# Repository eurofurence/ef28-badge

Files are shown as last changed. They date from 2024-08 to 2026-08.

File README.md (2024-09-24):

# Eurofurence 28 Cyber Badge

The cyber LED-Badge is a unique piece of wearable tech. At its core is a rigid
PCB (printed circuit board), assembled with electronic components, carefully
designed to be both functional and visually striking. On the back, you’ll find
a battery pack that powers the badge, ensuring that it can light up in a
spectrum of vibrant colors throughout the event.

The badge features 17 RGB LEDs, which can be controlled to display different
colors and patterns, allowing you to customize your experience. Whether you
want to flash your favorite colors, sync up with others, or simply let your
badge pulse with light as you move through the convention, the choice is yours.

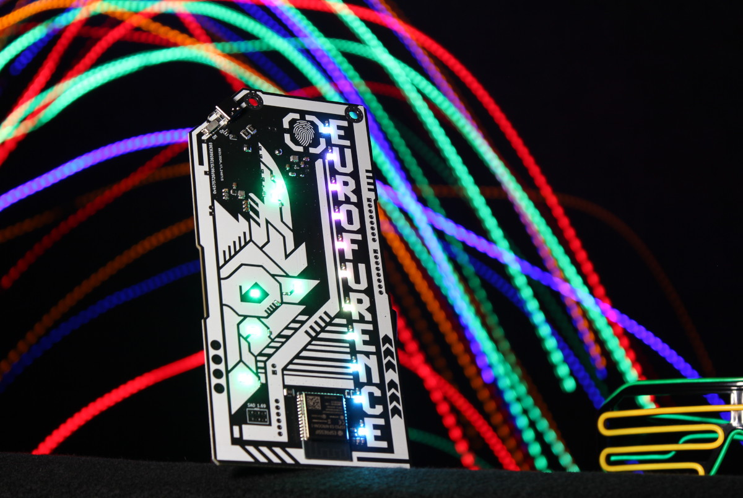
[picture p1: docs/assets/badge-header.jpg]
Picture of the badge


## Technical Details

You can find the full schematics and PCB files in the
[Hardware Details](#hardware-details) section.

- Height: 15.9 cm
- Width: 7.7 cm
- Weight (w/o batteries): 56 g
- Weight (with batteries): ~126 g
- LEDs: 17x WS2812B RGB LEDs
- CPU: ESP32-S3-WROOM-1-N16R8 (Dual-Core, 16MB of Flash, Bluetooth, Wi-Fi)
- Battery holder: 3x AA batteries
- Runtime: Depending on the operation mode and used features, several to many hours
- Unpopulated headers: 2x8 GPIO, SAO 1.69
- User input: 2 touch buttons
- Attachment: Dual-nylon-loop lanyard (included)
- Connectivity: USB-C connector for powering or programming
- Power: Mechanical power switch

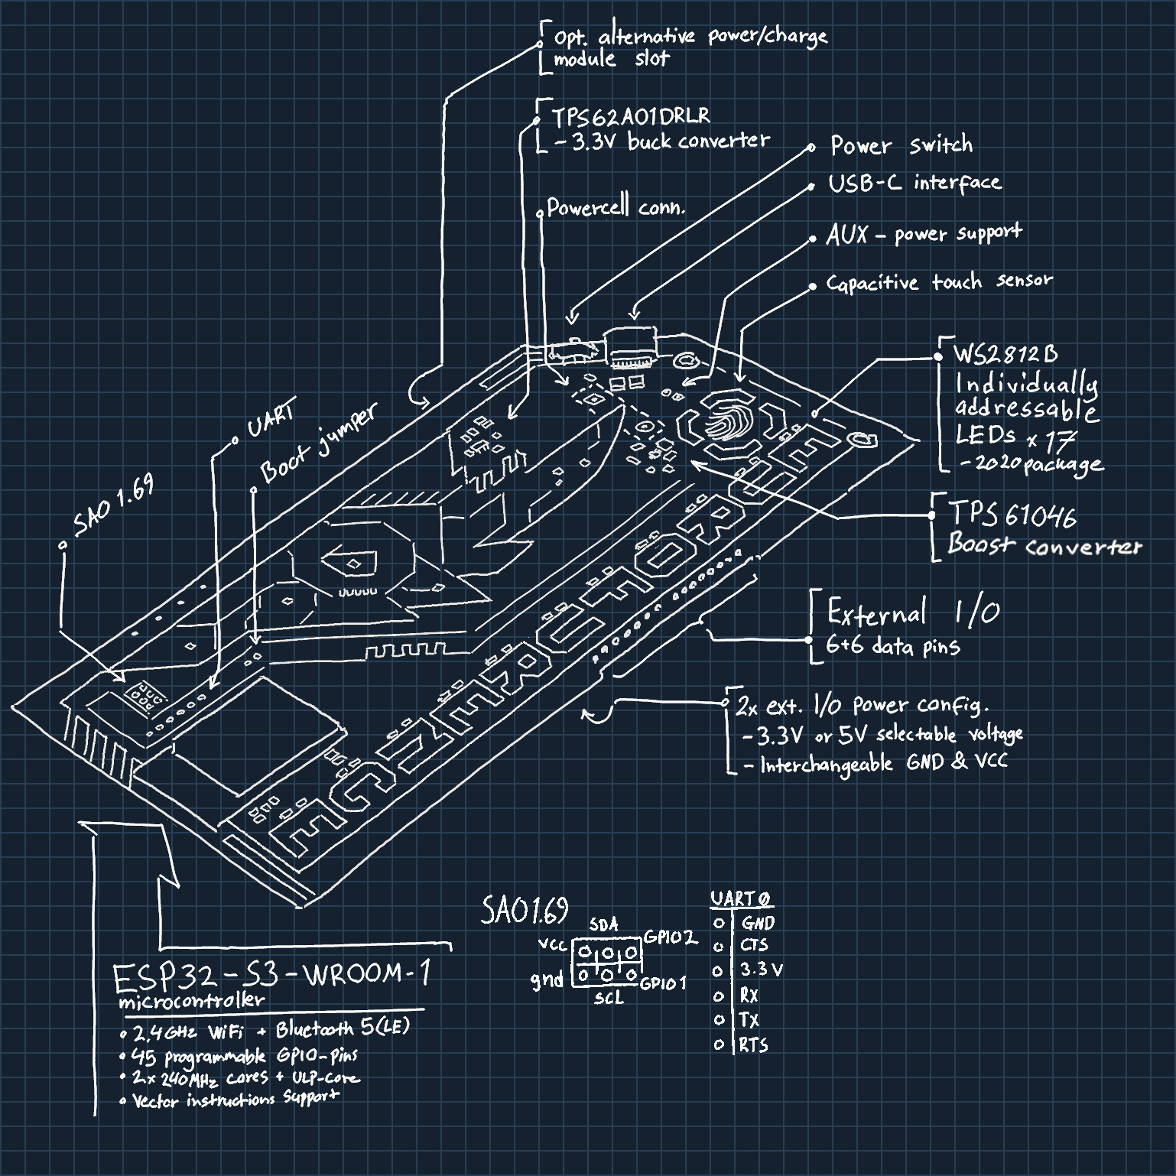
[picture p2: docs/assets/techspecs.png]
Technical drawing of the badge


# Usage and features

See this page: [How to use your badge](https://www.eurofurence.org/EF28/badge/manual)

## Serial Output / Logging

The badge logs most of its actions and current state onto the serial USB
console. It is available after connecting the badge via USB to your computer
and uses 115200 Baud 8N1.

To read the serial output you can use the serial monitor of your choice, for
example, the integrated serial monitor within VS Code (`CTRL + ALT + S`):

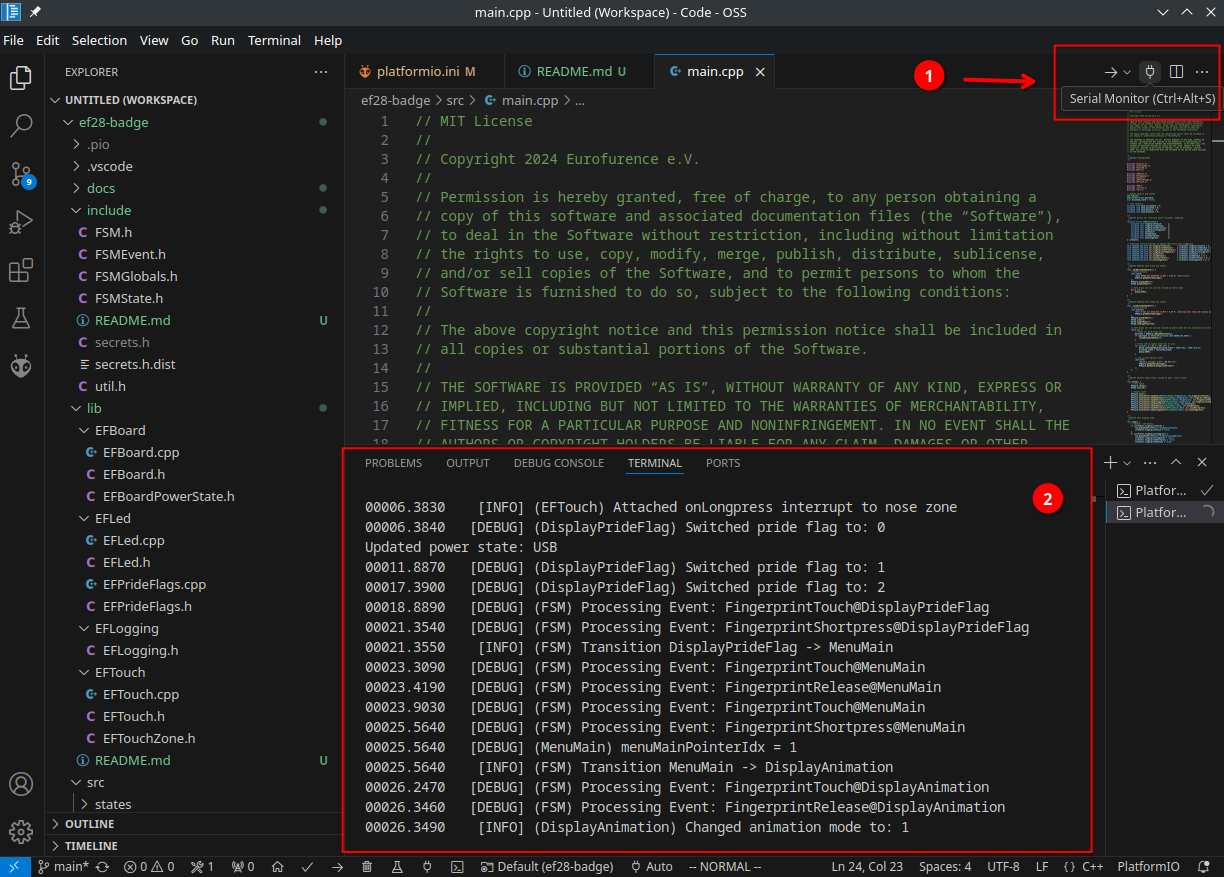
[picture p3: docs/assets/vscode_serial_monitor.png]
Screenshot: Using the serial monitor of VS Code


You can also use your favorite serial monitor, for example [minicom](https://salsa.debian.org/minicom-team/minicom):
`minicom -D /dev/ttyACM0 -b 115200`

## Note on LED brightness

You can configure the brightness of your badge, see the manual [How to use your badge](https://www.eurofurence.org/EF28/badge/manual). If you modify your firmware, do not push the LEDs too hard. We limited the brightness on purpose to around 45 of 255 since the 5V boot converter cannot handle more. If you use just one color channel, values up to 100/255 might work. But they are plenty bright at 45 of 255. Higher values cause the 5V rail to break down and the LEDs start flickering badly.

# Building Your Own Firmware

The badge firmware is built using [PlatformIO](https://platformio.org/), an
extension for [Visual Studio Code](https://code.visualstudio.com/) that allows
beginners to quickly get hacking.

### Building with Visual Studio Code (VCS)

To set up your development environment, you need to:

1. Install Visual Studio Code and PlatformIO, as described in the official
   [PlatformIO documentation](https://docs.platformio.org/en/latest/integration/ide/vscode.html#installation)
2. Clone this repository to a suitable location (here: `~/git/ef28-badge`)
3. Open the project under `~/git/ef28-badge` using the PlatformIO IDE
4. Copy `include/secrets.h.dist` to `include/secrets.h` and adjust as needed
5. Execute the build by pressing the build button (1) or using the hotkey (`CTRL + ALT + B`)
6. Check that your build was successful (2)

_Note: The first build can take a while since additional tools and libraries
may need to be downloaded_

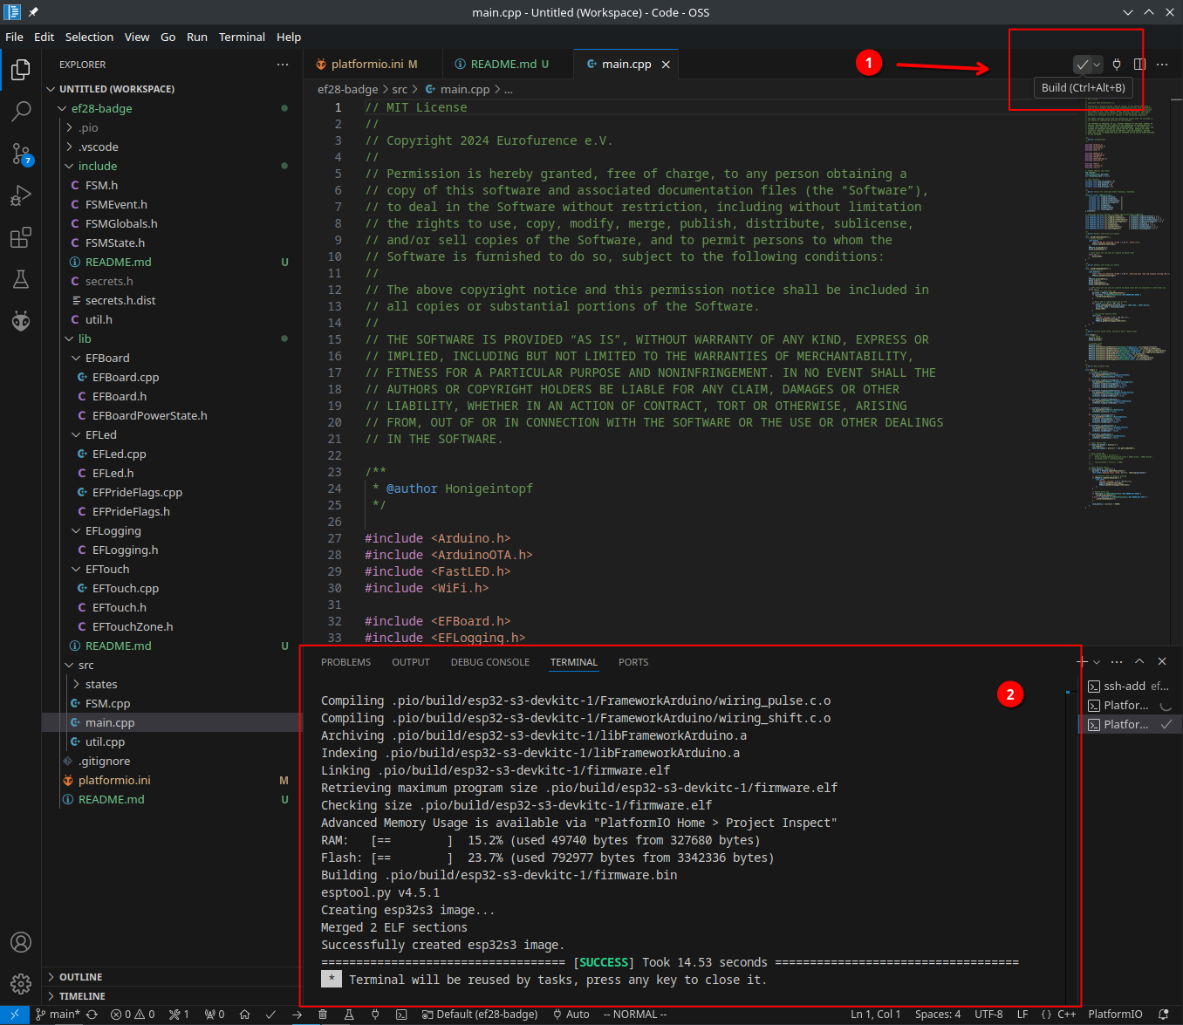
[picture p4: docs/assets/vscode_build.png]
Screenshot: Building the firmware using VS Code


### Building from CLI

You can archive most things with the `pio` command from PlatformIO.

* Build firmware: `pio run`
* Upload firmware: `pio run --target upload`
* Clean generated files: `pio run --target clean`
* Attach serial monitor: `pio device monitor`

## Component Overview

The core of this firmware is implemented as a tick-based finite state machine
(FSM). Each operation mode is reflected by a corresponding FSM state.
Interrupts, e.g., from touch zones, trigger events which will be processed by
the FSM in the order they occurred during each tick. Every FSM state can define
its own tick rate. Board features, such as LEDs and touch zones, are available
via easy to use high-level APIs (see `lib/`).

A quick overview of the firmware components:

- `main.cpp`: The main entry point for the firmware. Initializes everything and
  ignites the FSM.
- `include/`: C++ headers
- `include/secrets.h(.dist)`: Custom defines for Wi-Fi and OTA
- `lib/EFBoard/`: Low-level initialization and power management
- `lib/EFLed/`: High-level interface to board LEDs, uses
  [FastLED](https://fastled.io/) under the hood
- `lib/EFLogging/`: Basic serial logging facilities
- `lib/EFTouch/`: High-level interface to touch sensors
- `src/FSM.cpp`: Implementation of the FSM logic
- `src/states/`: Implementation of all FSM states

## Flashing

After you've built your firmware, you can flash it by either connecting the
badge via USB to your computer, or by using over-the-air (OTA) updates.

_Note: OTA updates are only supported after an initial flash using a USB
connection_

### USB

To flash the firmware via USB, you need to:

1. Have a successful build of your firmware
2. Connect the badge via USB to your computer
3. **Close all serial monitors** that use the badges USB device
4. Click the upload button (1) or use the hotkey (`CTRL + ALT + U`)
5. Wait for the flashing to finish (2). Your badge will reboot after flashing.

_Note: Linux users might need to install the
[PlatformIO udev rules](https://docs.platformio.org/en/stable//core/installation/udev-rules.html)
prior to the first flashing._

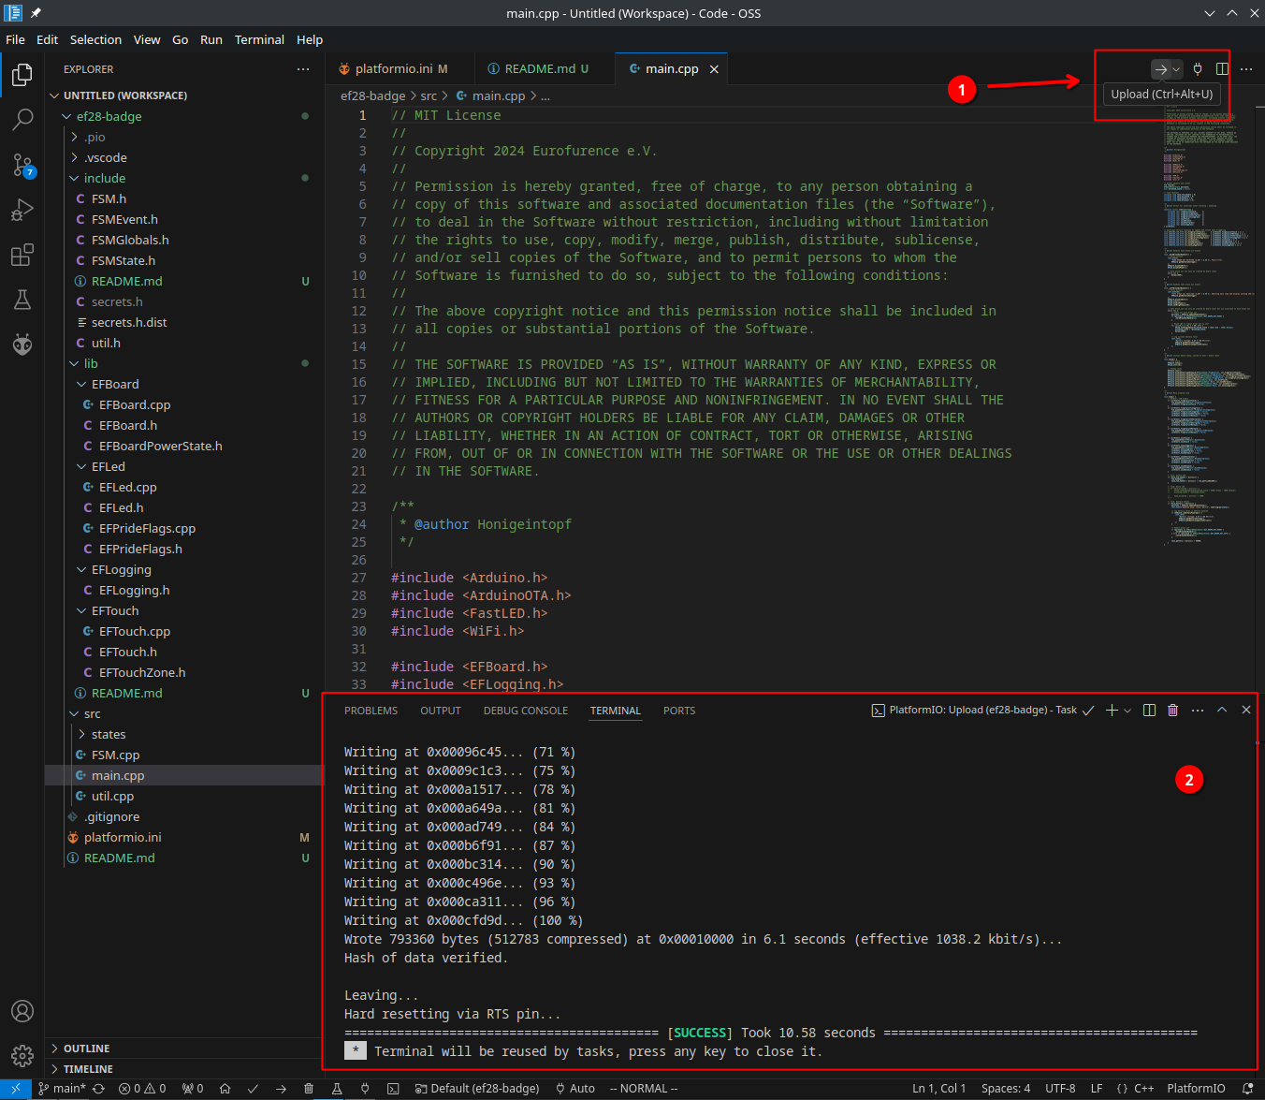
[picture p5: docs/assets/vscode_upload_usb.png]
Screenshot: Flashing the firmware via USB using VS Code


#### Notes and Pitfalls

If you encounter issues flashing via USB, try the following:

* Some USB cables or ports are flaky. Try a different USB port or change the
  USB-C -> USB-C cable to a USB-A -> USB-C or vice versa.
* Make sure no program is opening the serial port while you flash. For example
  serial monitors in auto-connect mode.
* If it still fails, bridge the boot-pins when turning on. The badge should
  load into a simple bootloader and wait.

### Over-the-Air Updates (OTA)

If you want to flash the badge using over-the-air updates (OTA), it must be
connected to the same Wi-Fi network as your computer.

To flash a badge using OTA, you need to:

1. Make sure to have the correct Wi-Fi credentials supplied in `include/secrets.h`
2. Determine the badge IP address
    - This can be done by connecting your badge to your computer, opening the
      serial monitor, and letting it connect to your Wi-Fi. After a successful
      connection, the badge will print its IP and MAC addresses to the serial console.
3. Uncomment all `upload_*` entries in your `platformio.ini` and adjust
   `upload_port` to the IP address of your badge.
4. Ensure that the badge is in OTA mode
5. Click the upload button or use the hotkey (`CTRL + ALT + U`)
6. Wait for the flashing to finish. The badge will display the OTA progress
   using the LED bar, and the dragon eye will flash three times after a
   successful OTA update.

# Hardware Details

All hardware details, schematics, and PCB files of the badge are released as
[Open Source Hardware](https://www.oshwa.org/). Feel free to share, use, remix,
and extend them to your likings.

You can find the full [KiCad](https://www.kicad.org/) files inside the
`hardware` directory.

For convenience, here is an exported PDF version of the schematics:

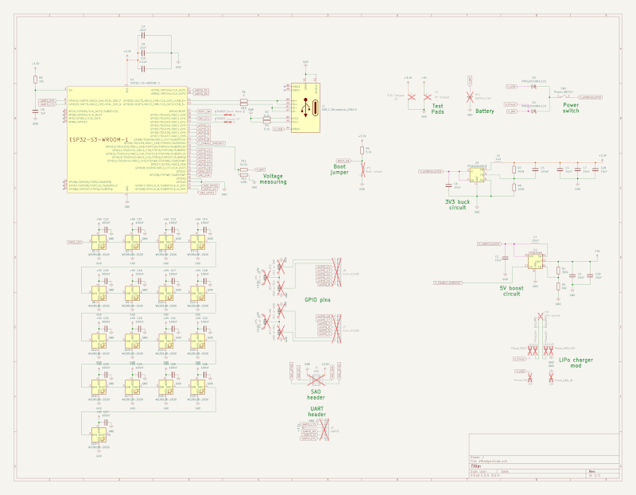
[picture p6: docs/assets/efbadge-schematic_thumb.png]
Screenshot: Schematics thumbnail


# Releases

The release-versions are based on [CalVer](https://calver.org/), with the pattern `vYYYY.MM.DD(-SUB)` where `SUB` is for potential sub-daily releases.

# Useful links

* ESP32-S3 Pin-out and functions: https://github.com/atomic14/esp32-s3-pinouts

# Credits

This badge was designed, crafted and programmed with much love and dedication
by: [DarkRat](https://github.com/dunkelratte), [Token](https://github.com/TokenRat),
[Irah](https://github.com/tridekdu), [Honigeintopf](https://github.com/ngandrass).

The wonderful artwork is done by [Fleeks](https://www.furaffinity.net/user/fleeks).

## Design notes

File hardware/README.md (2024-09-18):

# Hardware

This is a [KiCad](https://www.kicad.org/) project.

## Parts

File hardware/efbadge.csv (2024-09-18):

Comment | Designator | Footprint | LCSC
Battery_Cell | BT1 | Battery:BatteryHolder_TruPower_BH-331P_3xAA
CS2012X5R475K250NRE | C1,C4 | Capacitor_SMD:C_0805_2012Metric | C2918489
0.1uF | C10 | Capacitor_SMD:C_0603_1608Metric | C2846678
GRM188B30J226MEA0D | C2 | Capacitor_SMD:C_0603_1608Metric | C15500
1uF | C3,C8 | Capacitor_SMD:C_0603_1608Metric | C309479
29pF | C5 | Capacitor_SMD:C_0603_1608Metric | C880276
160pF | C6 | Capacitor_SMD:C_0603_1608Metric | C565568
10uF | C7 | Capacitor_SMD:C_0603_1608Metric
22uF | C9 | Capacitor_SMD:C_0603_1608Metric | C15500
WS2812B-2020 | D1,D2 | LED_SMD:LED_WS2812B-2020-Original_PLCC4_2.0x2.0mm | C965555
PMEG2010BEA,115 | D3,D4,D5 | Diode_SMD:D_SOD-323 | C455041
USB_C_Receptacle_USB2.0 | J1 | Connector_USB:USB_C_Receptacle_G-Switch_GT-USB-7010ASV | C165948
5V Testpad | J2 | Connector_PinHeader_2.54mm:PinHeader_1x02_P2.54mm_Vertical
3.3V Testpad | J3 | Connector_PinHeader_2.54mm:PinHeader_1x02_P2.54mm_Vertical
CWCI0603F-4R7KT | L1,L2 | Inductor_SMD:L_0603_1608Metric | C917344
27 | R1,R2 | Resistor_SMD:R_0603_1608Metric | C4197
5.1k | R3,R4 | Resistor_SMD:R_0603_1608Metric | C445832
200k | R5 | Resistor_SMD:R_0603_1608Metric | C394540
620k | R6 | Resistor_SMD:R_0603_1608Metric | C220714
550k | R7 | Resistor_SMD:R_0603_1608Metric | C2933236
100k | R8 | Resistor_SMD:R_0603_1608Metric | C2934392
10k | R9 | Resistor_SMD:R_0603_1608Metric | C209220
Power_SWITCH | SW1 | Button_Switch_SMD:SW_SPDT_PCM12 | C128955
ESP32-S3-WROOM-1 | U1 | PCM_Espressif:ESP32-S3-WROOM-1 | C2980297
TPS61040DDC | U2 | Package_TO_SOT_SMD:SOT-23-5 | C2678707
TPS62200DBV | U3 | Package_TO_SOT_SMD:SOT-23-5 | C9048

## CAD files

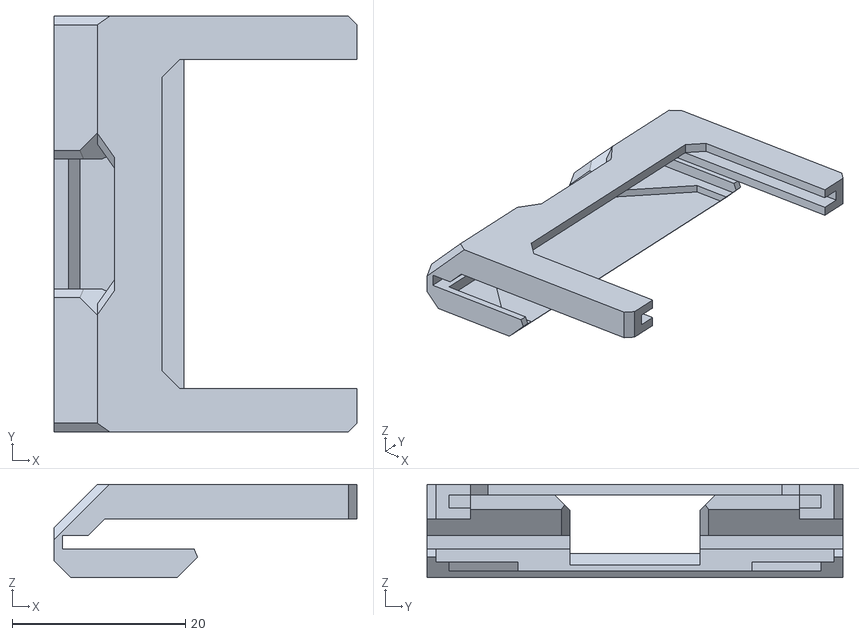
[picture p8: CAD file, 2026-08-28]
hardware/3dprint/oled_mount.stl
35.0 x 48.0 x 10.8

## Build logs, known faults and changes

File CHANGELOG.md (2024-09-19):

# EF28 Cyber LED Badge

## v2024-09-19-beta

* Add beta game mode R. By pressing the nose you transmit your color to nearby badges. The more nose-boop, the more you 'spread' you color.

## v2024.09.07

* Initial release

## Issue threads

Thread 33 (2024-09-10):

Battery measurement is off

TokenRat, 2024-09-10:
**What is the problem**

Currently, getBatteryVoltage uses a factor for the internal ADC of 3.5V instead of 3.3v, what it should be. The reason is: If we use 3.5 as the factor, when on batteries, we go into soft-brownout detection at around 3.36V, which is right what we want. (Measured with multimeter on the batteries). Why is this? What is wrong with the formular?

Also, when on USB and monitoring serial, we get values which a very off. If we use 3.3 as a factor, we measure almost 0.2V too little. Using 3.5 as the factor still does not get the perfect result.

Maybe someone can spot the mistake…

Code: https://github.com/eurofurence/ef28-badge/blob/eefaa05d0f5d9e829db166581c0f541a6f17a42c/lib/EFBoard/EFBoard.cpp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

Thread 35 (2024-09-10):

Using the ULP processor for LED animations

TokenRat, 2024-09-10:
**Your feature request**

The ULP is *barely* too slow to bit-bang the WS2812 LEDs according to the timing specs. But who knows, how tolerant they are? With some well-timed NOPs or some other tricks, we might be able to draw patterns per GPIO from the ULP.

The main processor then would write the patterns into flash and go to sleep, while the ulp reads them and displays them, until wakeup. This would reduce the power consumption and be a pretty cool trick. I played around a bit already, but got no results so far.

Of course, any WiFi or other function would not work in this state.

nponsard, 2024-10-10:
I managed to control the leds from the ULP https://github.com/nponsard/ef28-badge/blob/rust-no-std/coprocessor/src/main.rs .

I made it so it generates the code to drive all the leds and then execute it so the timing is always the same.

To initialize I do
```asm
lui	a2,0x80000
lui	a1,0xa
addi    a1,a1,1024
```
so I can turn on and off the gpio 21 with a 2-bytes instruction instead of a 4-bytes instructions

Turn on :
```
sw      a2,4(a1)
```

Turn off :

```asm
sw      a2,8(a1)
```

then I use NOP instructions as delays:
- 0 for T0H (bit 0, number of NOP to wait before turning off)
- 2 for T1H (bit 1, number of NOP to wait before turning off)
- 4 for T0L (bit 0, number of NOP to wait before encoding the next bit)
- 2 for T1L (bit 1, number of NOP to wait before encoding the next bit)

Generating a program to drive the 17 leds uses 4 908 bytes.
I tried previously with loops but it messes up the timing.

For example , to send 010 :
```asm
// configure the registers once
lui	a2,0x80000
lui	a1,0xa
addi    a1,a1,1024
//send the data
sw      a2,4(a1) // turn on
sw      a2,8(a1) // turn off
nop
nop
nop
nop
sw      a2,4(a1) // turn on
nop
nop
sw      a2,8(a1) // turn off
nop
nop
sw      a2,4(a1) // turn on
sw      a2,8(a1) // turn off
nop
nop
nop
nop
```

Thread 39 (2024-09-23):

Complete USB-Driven mode

MeisterLi, 2024-09-23:
**Your feature request**
I would like to put the EF LED Bade into my PC and drive it internally via USB there. It would be nice if we could issue commands via that serial connection to change patterns/display modes. I am not very versed with PlatformIO and C++ and I have looked into it a bit to see if I could find this option, but I wasn't able to figure out if this was a feature already.

I was able to connect the device via Wifi to my home network as well, but from what I can see, that does not allow setting anything yet either? Thanks for answering! :)

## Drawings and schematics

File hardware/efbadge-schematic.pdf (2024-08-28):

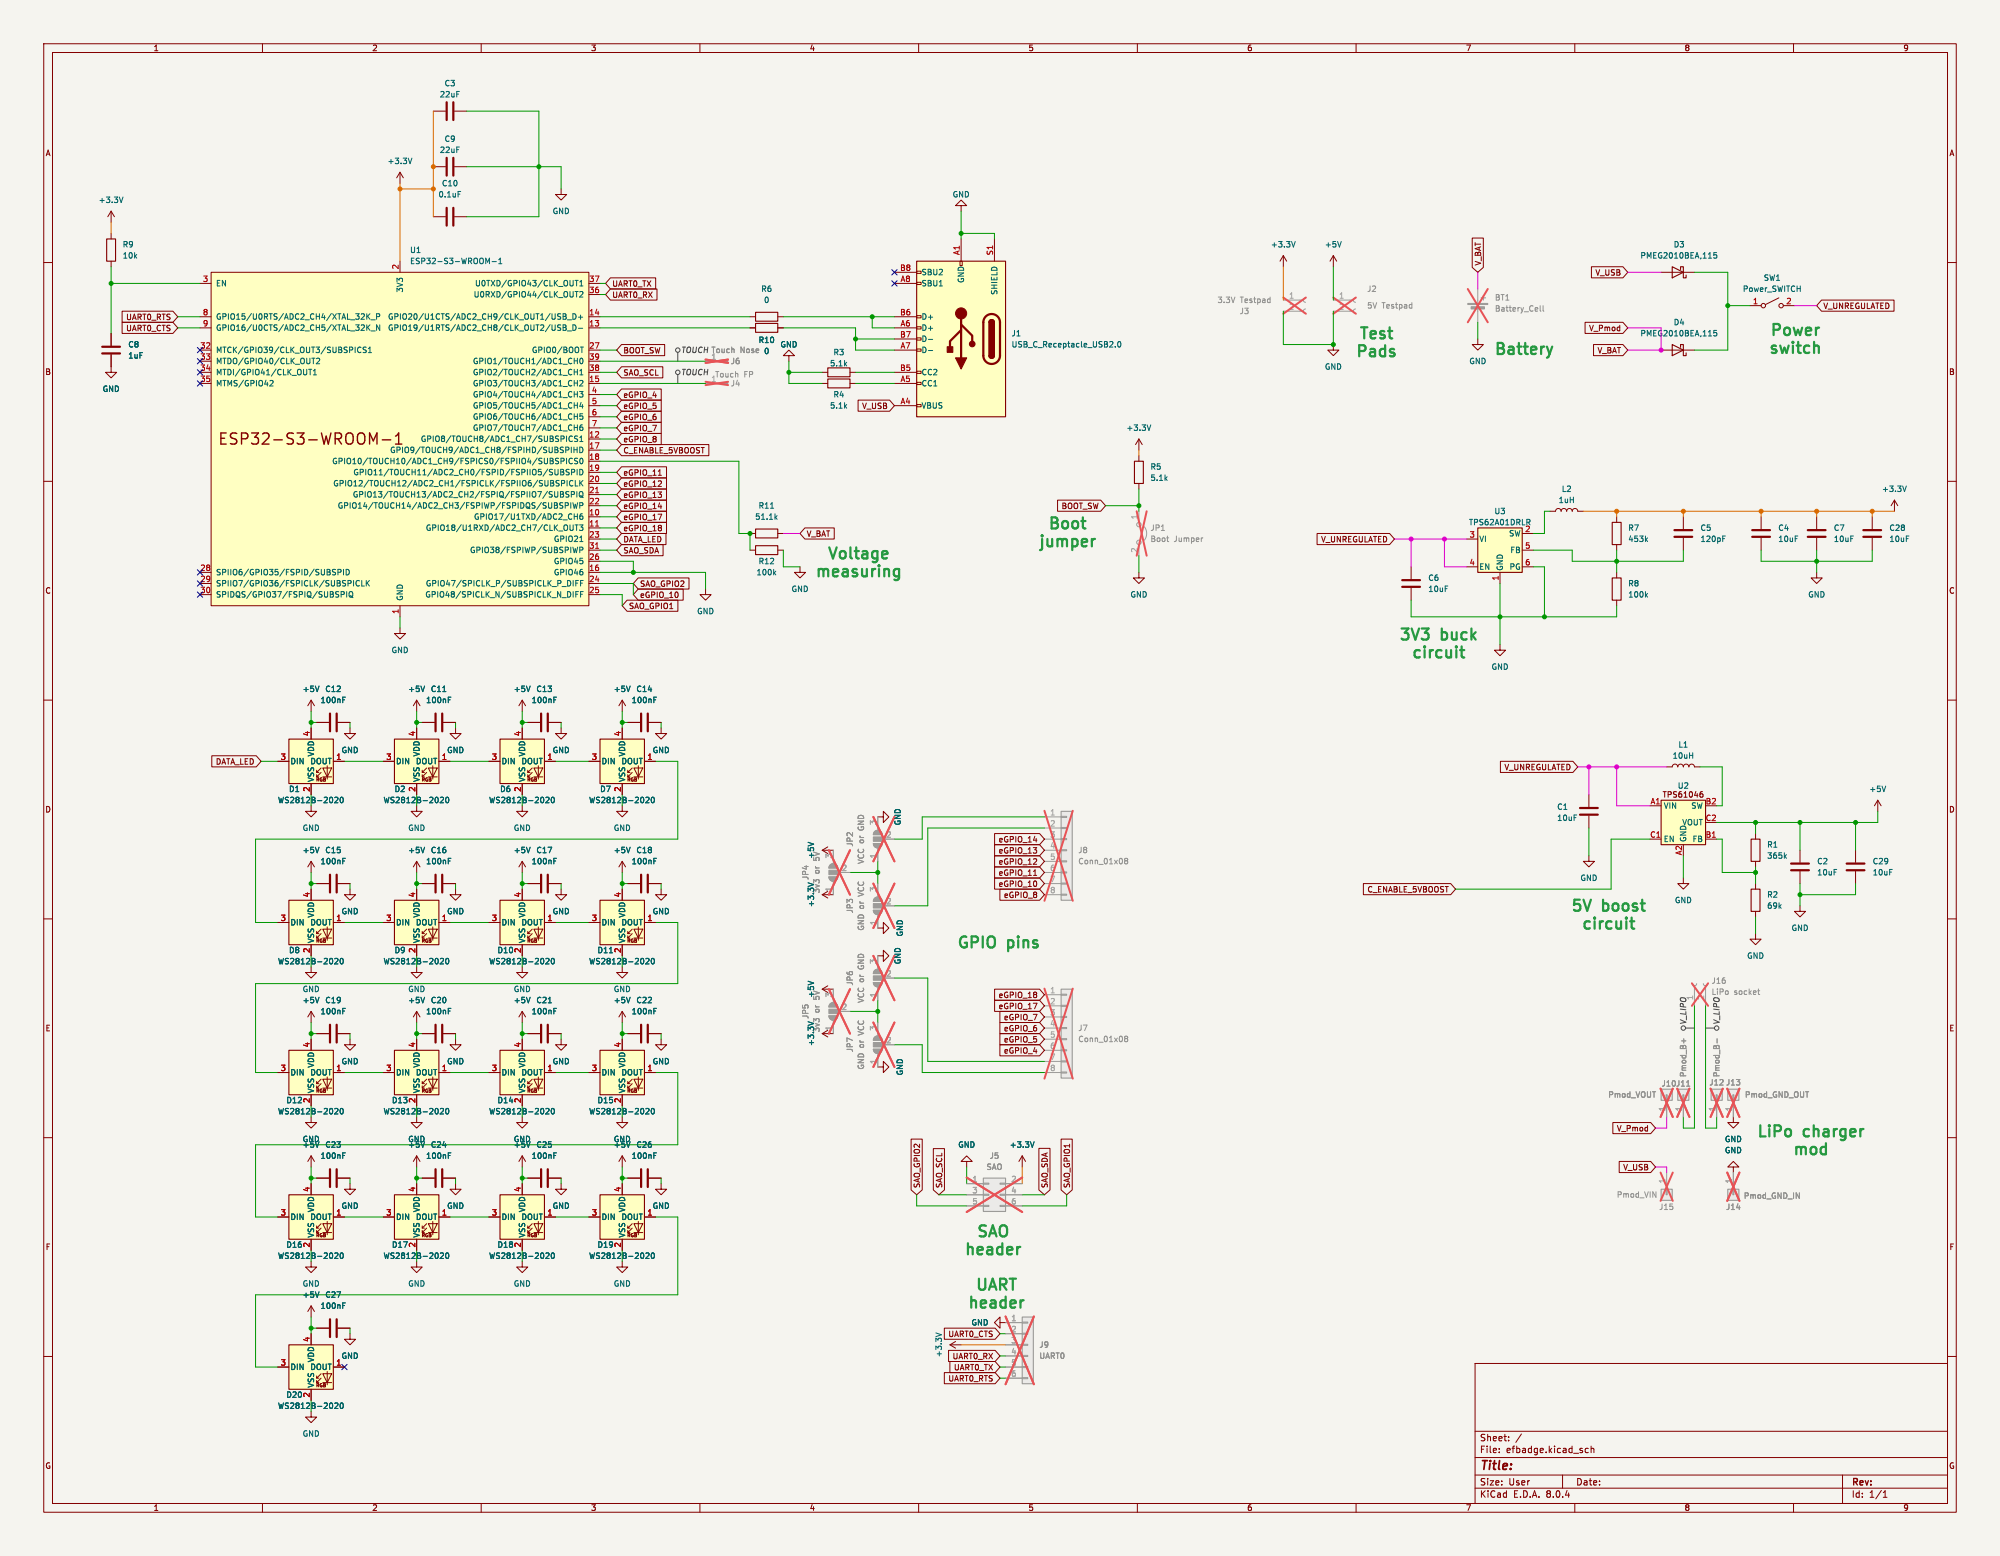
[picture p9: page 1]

2 GPIO12/TOUCH12/ADC2_CH1/FSPICLK/FSPIIO6/SUBSPICLK 20 GPIO13/TOUCH13/ADC2_CH2/FSPIQ/FSPIIO7/SUBSPIQ 21 GPIO14/TOUCH14/ADC2_CH3/FSPIWP/FSPIDQS/SUBSPIWP 22 GPIO21 23 GPIO47/SPICLK_P/SUBSPICLK_P_DIFF 24 GPIO48/SPICLK_N/SUBSPICLK_N_DIFF 25 GPIO45 26 GPIO0/BOOT 27 SPIIO6/GPIO35/FSPID/SUBSPID 28 SPIIO7/GPIO36/FSPICLK/SUBSPICLK 29 EN 3 SPIDQS/GPIO37/FSPIQ/SUBSPIQ 30 GPIO38/FSPIWP/SUBSPIWP 31 MTCK/GPIO39/CLK_OUT3/SUBSPICS1 32 MTDO/GPIO40/CLK_OUT2 33 MTDI/GPIO41/CLK_OUT1 34 MTMS/GPIO42 35 U0RXD/GPIO44/CLK_OUT2 36 U0TXD/GPIO43/CLK_OUT1 37 GPIO2/TOUCH2/ADC1_CH1 38 GPIO1/TOUCH1/ADC1_CH0 39 GPIO4/TOUCH4/ADC1_CH3 4 GPIO5/TOUCH5/ADC1_CH4 5 GPIO6/TOUCH6/ADC1_CH5 6 GPIO7/TOUCH7/ADC1_CH6 7 GPIO15/U0RTS/ADC2_CH4/XTAL_32K_P 8 GPIO16/U0CTS/ADC2_CH5/XTAL_32K_N 9 U1ESP32-S3-WROOM-1

1 GPIO17/U1TXD/ADC2_CH6 10 GPIO18/U1RXD/ADC2_CH7/CLK_OUT3 11 GPIO8/TOUCH8/ADC1_CH7/SUBSPICS1 12 GPIO19/U1RTS/ADC2_CH8/CLK_OUT2/USB_D- 13 GPIO20/U1CTS/ADC2_CH9/CLK_OUT1/USB_D+ 14 GPIO3/TOUCH3/ADC1_CH2 15 GPIO46 16 GPIO9/TOUCH9/ADC1_CH8/FSPIHD/SUBSPIHD 17 GPIO10/TOUCH10/ADC1_CH9/FSPICS0/FSPIIO4/SUBSPICS0 18 GPIO11/TOUCH11/ADC2_CH0/FSPID/FSPIIO5/SUBSPID 19 3V3

1 SW 2 VI 3 EN 4 FB 5 PG 6 U3 TPS62A01DRLR R7

3GND GND JP3 GND or VCC

3 JP2 VCC or GND GND GND GND

Id: 1/1 Title: File: efbadge.kicad_sch Sheet: / GND

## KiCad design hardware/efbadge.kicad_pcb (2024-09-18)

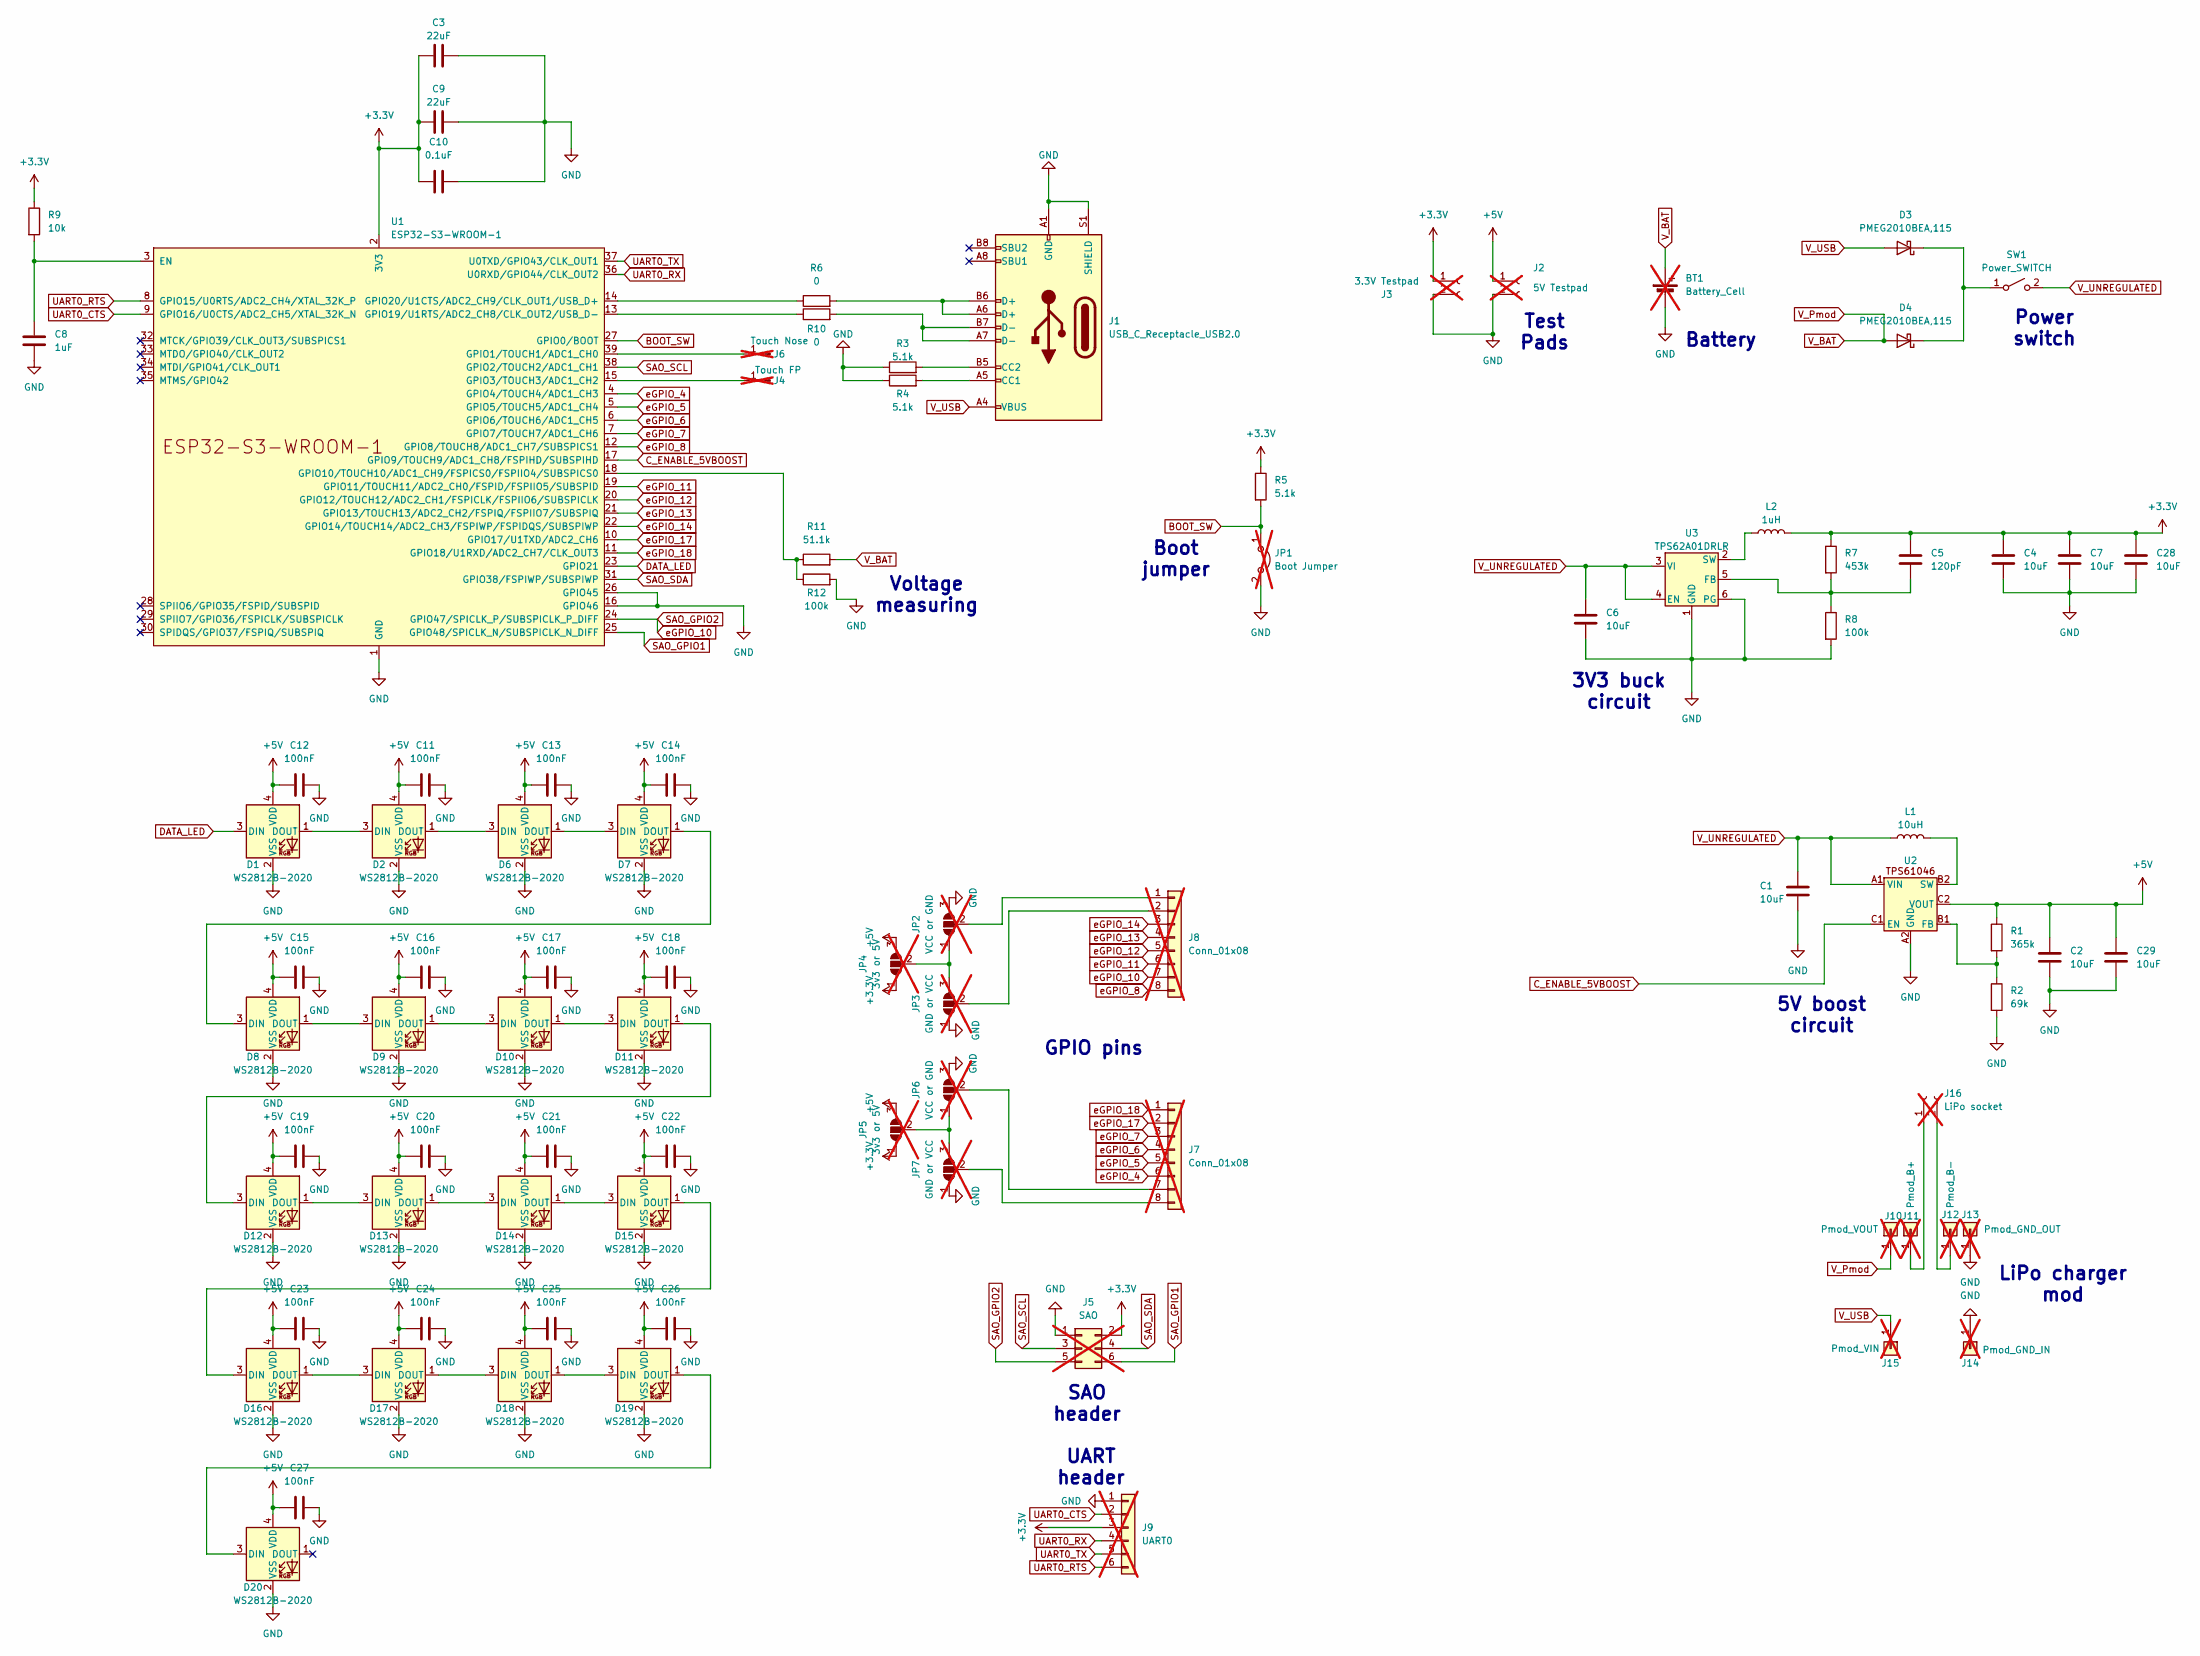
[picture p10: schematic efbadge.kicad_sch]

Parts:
BT1: Battery_Cell; BatteryHolder_TruPower_BH-331P_3xAA; Digikey 36-2464-ND; not fitted
C1, C2, C4, C6, C7, C28, C29: 10uF; C_0603_1608Metric; LCSC C182375
C3, C9: 22uF; C_0603_1608Metric; LCSC C15500
C5: 120pF; C_0603_1608Metric; LCSC C61636
C8: 1uF; C_0603_1608Metric; LCSC C309479
C10: 0.1uF; C_0603_1608Metric; LCSC C2846678
C11, C12, C13, C14, C15, C16, C17, C18, C19, C20, C21, C22, C23, C24, C25, C26, C27: 100nF; C_0603_1608Metric_Pad1.08x0.95mm_HandSolder; LCSC C14663
D1, D2, D6, D7, D8, D9, D10, D11, D12, D13, D14, D15, D16, D17, D18, D19, D20: WS2812B-2020; LED_WS2812B-2020_PLCC4_2.0x2.0mm; LCSC C965555
D3, D4: PMEG2010BEA,115; D_SOD-323; LCSC C455041
J1: USB_C_Receptacle_USB2.0; USB_C_Receptacle_G-Switch_GT-USB-7010ASV; LCSC C165948
J2: 5V Testpad; PinHeader_1x02_P2.54mm_Vertical; not fitted
J3: 3.3V Testpad; PinHeader_1x02_P2.54mm_Vertical; not fitted
J4: Touch FP; Badge_Touch; not fitted
J5: SAO; PinHeader_2x03_P2.54mm_Vertical; not fitted
J6: Touch Nose; Badge_Touch; not fitted
J7, J8: Conn_01x08; PinHeader_1x08_P2.54mm_Horizontal; not fitted
J9: UART0; PinHeader_1x06_P2.54mm_Vertical; not fitted
J10: Pmod_VOUT; PinHeader_1x01_P2.54mm_Vertical; not fitted
J11: Pmod_B+; PinHeader_1x01_P2.54mm_Vertical; not fitted
J12: Pmod_B-; PinHeader_1x01_P2.54mm_Vertical; not fitted
J13: Pmod_GND_OUT; PinHeader_1x01_P2.54mm_Vertical; not fitted
J14: Pmod_GND_IN; PinHeader_1x01_P2.54mm_Vertical; not fitted
J15: Pmod_VIN; PinHeader_1x01_P2.54mm_Vertical; not fitted
J16: LiPo socket; JST_PH_S2B-PH-K_1x02_P2.00mm_Horizontal; not fitted
JP1: Boot Jumper; PinHeader_2x01_P2.54mm_Vertical; not fitted
JP2, JP6: VCC or GND; SolderJumper-3_P1.3mm_Open_RoundedPad1.0x1.5mm; not fitted
JP3, JP7: GND or VCC; SolderJumper-3_P1.3mm_Open_RoundedPad1.0x1.5mm; not fitted
JP4, JP5: 3v3 or 5V; SolderJumper-3_P1.3mm_Open_RoundedPad1.0x1.5mm; not fitted
L1: 10uH; L_1008_2520Metric; LCSC C701155
L2: 1uH; L_1008_2520Metric; LCSC C435392
R1: 365k; R_0402_1005Metric; LCSC C3016042
R2: 69k; R_0805_2012Metric; LCSC C2684588
R3, R4, R5: 5.1k; R_1210_3225Metric; LCSC C830191
R6, R10: 0; R_0805_2012Metric; LCSC C844811
R7: 453k; R_0603_1608Metric; LCSC C861412
R8, R12: 100k; R_0603_1608Metric; LCSC C227434
R9: 10k; R_0603_1608Metric; LCSC C209220
R11: 51.1k; R_0402_1005Metric; LCSC C100466
SW1: Power_SWITCH; SW_SPDT_PCM12; LCSC C128955
U1: ESP32-S3-WROOM-1; LCSC C2913201
U2: Texas_DSBGA-6_0.855x1.255mm_Layout2x3_P0.4mm_LevelC; LCSC C181551
U3: TPS62A01DRLR; SOT-563; LCSC C5157937

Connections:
+3.3V: C3.1, C4.1, C5.1, C7.1, C9.1, C10.1, C28.1, J3.1, J5.2, J9.3, JP4.1 (A), JP5.1 (A), L2.2, R5.1, R7.1, R9.1, U1.2 (3V3)
+5V: C2.1, C11.2, C12.2, C13.2, C14.2, C15.2, C16.2, C17.2, C18.2, C19.2, C20.2, C21.2, C22.2, C23.2, C24.2, C25.2, C26.2, C27.2, C29.1, D1.4 (VDD), D2.4 (VDD), D6.4 (VDD), D7.4 (VDD), D8.4 (VDD), D9.4 (VDD), D10.4 (VDD), D11.4 (VDD), D12.4 (VDD), D13.4 (VDD), D14.4 (VDD), D15.4 (VDD), D16.4 (VDD), D17.4 (VDD), D18.4 (VDD), D19.4 (VDD), D20.4 (VDD), J2.1, JP4.3 (B), JP5.3 (B), R1.1, U2.C2 (VOUT)
BOOT_SW: JP1.1 (A), R5.2, U1.27 (GPIO0/BOOT)
C_ENABLE_5VBOOST: U1.17 (GPIO9/TOUCH9/ADC1_CH8/FSPIHD/SUBSPIHD), U2.C1 (EN)
DATA_LED: D1.3 (DIN), U1.23 (GPIO21)
GND: BT1.2 (-), C1.2, C2.2, C3.2, C4.2, C6.2, C7.2, C8.2, C9.2, C10.2, C11.1, C12.1, C13.1, C14.1, C15.1, C16.1, C17.1, C18.1, C19.1, C20.1, C21.1, C22.1, C23.1, C24.1, C25.1, C26.1, C27.1, C28.2, C29.2, D1.2 (VSS), D2.2 (VSS), D6.2 (VSS), D7.2 (VSS), D8.2 (VSS), D9.2 (VSS), D10.2 (VSS), D11.2 (VSS), D12.2 (VSS), D13.2 (VSS), D14.2 (VSS), D15.2 (VSS), D16.2 (VSS), D17.2 (VSS), D18.2 (VSS), D19.2 (VSS), D20.2 (VSS), J1.A1 (GND), J1.A12 (GND), J1.B1 (GND), J1.B12 (GND), J1.S1 (SHIELD), J2.2, J3.2, J5.1, J9.1, J13.1, J14.1, JP1.2 (B), JP2.3 (B), JP3.1 (A), JP6.3 (B), JP7.1 (A), R2.2, R3.1, R4.1, R8.2, R12.2, U1.1 (GND), U1.16 (GPIO46), U1.26 (GPIO45), U1.40 (GND), U1.41 (GND), U2.A2 (GND), U3.1 (GND), U3.6 (PG)
unnamed: D1.1 (DOUT), D2.3 (DIN)
unnamed: D2.1 (DOUT), D6.3 (DIN)
unnamed: D3.1 (K), D4.1 (K), SW1.1 (A)
unnamed: D6.1 (DOUT), D7.3 (DIN)
unnamed: D7.1 (DOUT), D8.3 (DIN)
unnamed: D8.1 (DOUT), D9.3 (DIN)
unnamed: D9.1 (DOUT), D10.3 (DIN)
unnamed: D10.1 (DOUT), D11.3 (DIN)
unnamed: D11.1 (DOUT), D12.3 (DIN)
unnamed: D12.1 (DOUT), D13.3 (DIN)
unnamed: D13.1 (DOUT), D14.3 (DIN)
unnamed: D14.1 (DOUT), D15.3 (DIN)
unnamed: D15.1 (DOUT), D16.3 (DIN)
unnamed: D16.1 (DOUT), D17.3 (DIN)
unnamed: D17.1 (DOUT), D18.3 (DIN)
unnamed: D18.1 (DOUT), D19.3 (DIN)
unnamed: D19.1 (DOUT), D20.3 (DIN)
unnamed: J1.A5 (CC1), R4.2
unnamed: J1.B5 (CC2), R3.2
unnamed: J1.A6 (D+), J1.B6 (D+), R6.2
unnamed: J1.A7 (D-), J1.B7 (D-), R10.2
unnamed: J4.1, U1.15 (GPIO3/TOUCH3/ADC1_CH2)
unnamed: J6.1, U1.39 (GPIO1/TOUCH1/ADC1_CH0)
unnamed: J7.7, JP6.2 (C)
unnamed: J7.8, JP7.2 (C)
unnamed: J8.1, JP2.2 (C)
unnamed: J8.2, JP3.2 (C)
unnamed: J11.1, J16.1
unnamed: J12.1, J16.2
unnamed: JP2.1 (A), JP3.3 (B), JP4.2 (C)
unnamed: JP5.2 (C), JP6.1 (A), JP7.3 (B)
unnamed: C8.1, R9.2, U1.3 (EN)
unnamed: R11.1, R12.1, U1.18 (GPIO10/TOUCH10/ADC1_CH9/FSPICS0/FSPIIO4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)
unnamed: R10.1, U1.13 (GPIO19/U1RTS/ADC2_CH8/CLK_OUT2/USB_D-)
unnamed: R6.1, U1.14 (GPIO20/U1CTS/ADC2_CH9/CLK_OUT1/USB_D+)
unnamed: R1.2, R2.1, U2.B1 (FB)
unnamed: L1.2, U2.B2 (SW)
unnamed: C5.2, R7.2, R8.1, U3.5 (FB)
unnamed: L2.1, U3.2 (SW)
SAO_GPIO1: J5.6, U1.25 (GPIO48/SPICLK_N/SUBSPICLK_N_DIFF)
SAO_GPIO2: J5.5, J8.7, U1.24 (GPIO47/SPICLK_P/SUBSPICLK_P_DIFF)
SAO_SCL: J5.3, U1.38 (GPIO2/TOUCH2/ADC1_CH1)
SAO_SDA: J5.4, U1.31 (GPIO38/FSPIWP/SUBSPIWP)
UART0_CTS: J9.2, U1.9 (GPIO16/U0CTS/ADC2_CH5/XTAL_32K_N)
UART0_RTS: J9.6, U1.8 (GPIO15/U0RTS/ADC2_CH4/XTAL_32K_P)
UART0_RX: J9.4, U1.36 (U0RXD/GPIO44/CLK_OUT2)
UART0_TX: J9.5, U1.37 (U0TXD/GPIO43/CLK_OUT1)
V_BAT: BT1.1 (+), D4.2 (A), J10.1, R11.2
V_UNREGULATED: C1.1, C6.1, L1.1, SW1.2 (B), U2.A1 (VIN), U3.3 (VI), U3.4 (EN)
V_USB: D3.2 (A), J1.A4 (VBUS), J1.A9 (VBUS), J1.B4 (VBUS), J1.B9 (VBUS), J15.1
eGPIO_4: J7.6, U1.4 (GPIO4/TOUCH4/ADC1_CH3)
eGPIO_5: J7.5, U1.5 (GPIO5/TOUCH5/ADC1_CH4)
eGPIO_6: J7.4, U1.6 (GPIO6/TOUCH6/ADC1_CH5)
eGPIO_7: J7.3, U1.7 (GPIO7/TOUCH7/ADC1_CH6)
eGPIO_8: J8.8, U1.12 (GPIO8/TOUCH8/ADC1_CH7/SUBSPICS1)
eGPIO_11: J8.6, U1.19 (GPIO11/TOUCH11/ADC2_CH0/FSPID/FSPIIO5/S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)
eGPIO_12: J8.5, U1.20 (GPIO12/TOUCH12/ADC2_CH1/FSPICLK/FSPIIO6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)
eGPIO_13: J8.4, U1.21 (GPIO13/TOUCH13/ADC2_CH2/FSPIQ/FSPIIO7/S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)
eGPIO_14: J8.3, U1.22 (GPIO14/TOUCH14/ADC2_CH3/FSPIWP/FSPIDQS/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)
eGPIO_17: J7.2, U1.10 (GPIO17/U1TXD/ADC2_CH6)
eGPIO_18: J7.1, U1.11 (GPIO18/U1RXD/ADC2_CH7/CLK_OUT3)

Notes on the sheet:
GPIO pins
LiPo charger mod
Boot jumper
3V3 buck circuit
5V boost circuit
Voltage measuring
UART header
Battery
SAO header
Power switch
Test Pads

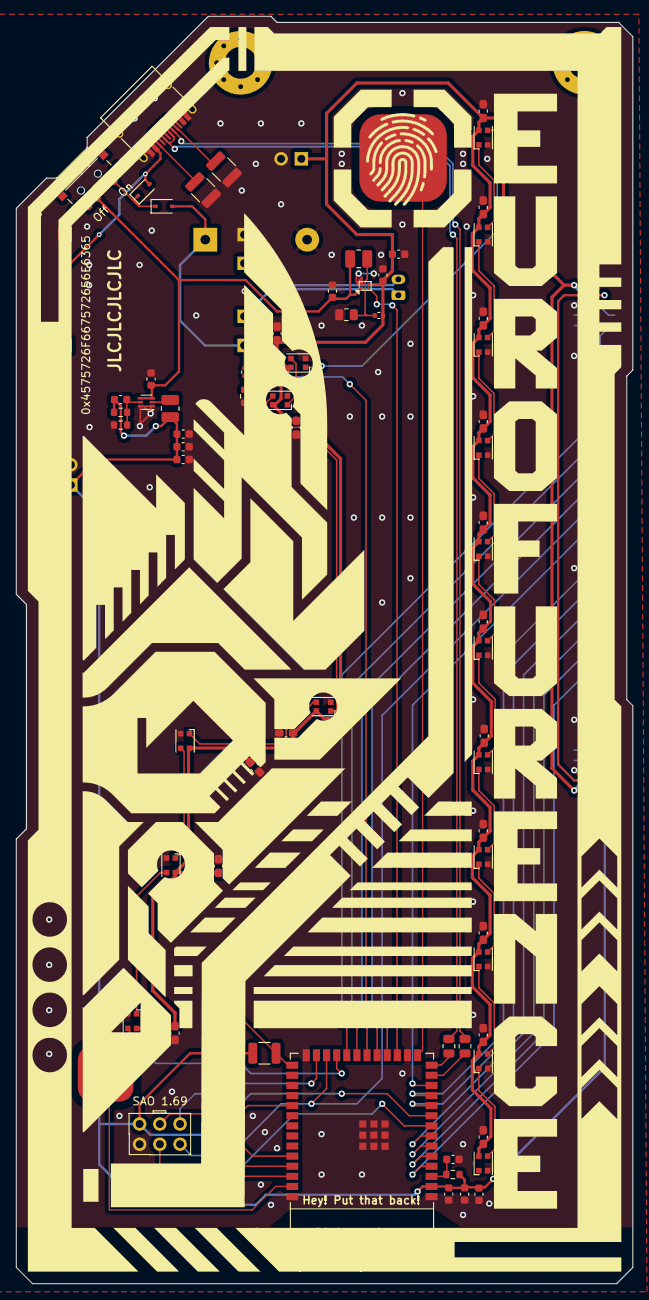
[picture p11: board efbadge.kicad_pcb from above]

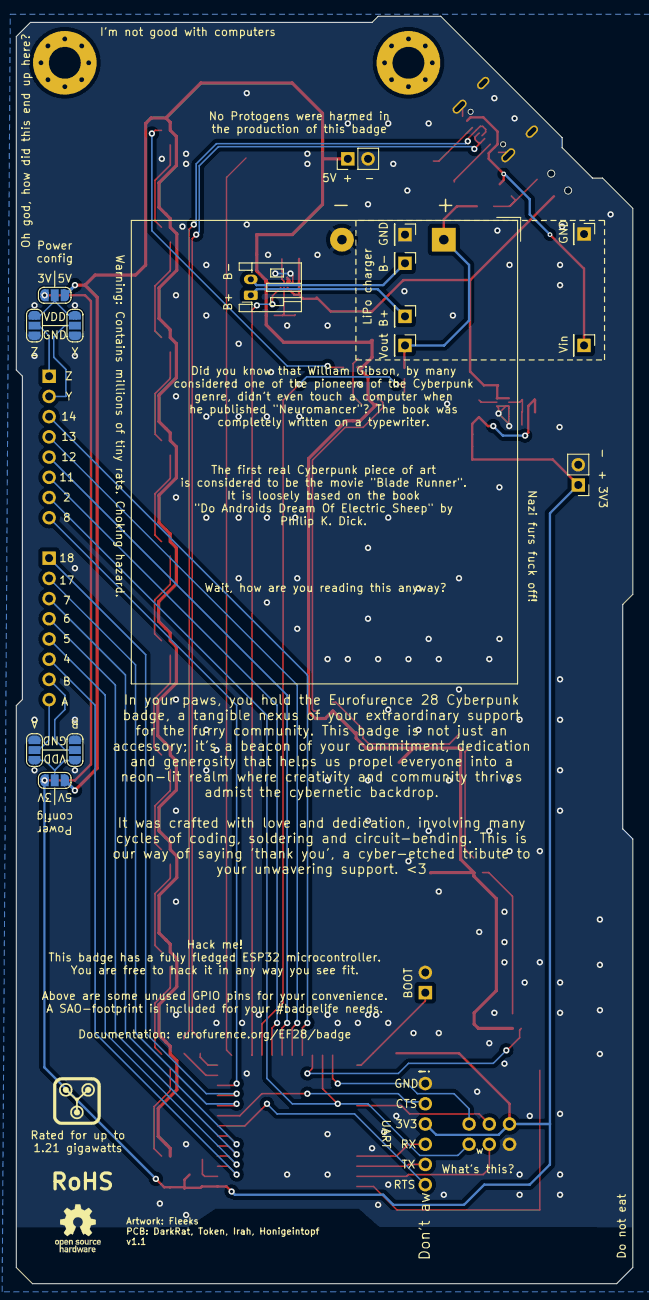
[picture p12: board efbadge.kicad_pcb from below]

Board: 2 copper layers, 77.5 x 159.3 mm, 93 parts (16 on the bottom side), 67 nets.

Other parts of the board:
Hole1, Hole2: MountingHole_4mm_Pad_Via
Ref**: Val**; fluxcondensator

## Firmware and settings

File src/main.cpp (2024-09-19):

// MIT License
//
// Copyright 2024 Eurofurence e.V. 
// 
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
/**
 * @author Honigeintopf
 */

#include <Arduino.h>
#include <ArduinoOTA.h>
#include <FastLED.h>
#include <WiFi.h>

#include <EFBoard.h>
#include <EFLogging.h>
#include <EFLed.h>
#include <EFTouch.h>

#include "FSM.h"
#include "FSMGlobals.h"
#include "util.h"

// Global objects and states
constexpr unsigned int INTERVAL_BATTERY_CHECK = 10000;
// Initializing the board with a brightness above 48 can cause stability issues!
constexpr uint8_t ABSOLUTE_MAX_BRIGHTNESS = 45;
FSM fsm(10);
EFBoardPowerState pwrstate;

// Task counters
unsigned long task_fsm_handle = 0;
unsigned long task_blinkled = 0;
unsigned long task_battery = 0;
unsigned long task_brownout = 0;

/**
 * @brief Struct for interrupt event tracking / handling
 */
volatile struct ISREventsType {
    unsigned char fingerprintTouch:      1;
    unsigned char fingerprintRelease:    1;
    unsigned char fingerprintShortpress: 1;
    unsigned char fingerprintLongpress:  1;
    unsigned char noseTouch:             1;
    unsigned char noseRelease:           1;
    unsigned char noseShortpress:        1;
    unsigned char noseLongpress:         1;
    unsigned char allShortpress:         1;
    unsigned char allLongpress:          1;
} isrEvents;

// Interrupt service routines to update ISR struct upon triggering
void ARDUINO_ISR_ATTR isr_fingerprintTouch()      { isrEvents.fingerprintTouch = 1; }
void ARDUINO_ISR_ATTR isr_fingerprintRelease()    { isrEvents.fingerprintRelease = 1; }
void ARDUINO_ISR_ATTR isr_fingerprintShortpress() { isrEvents.fingerprintShortpress = 1; }
void ARDUINO_ISR_ATTR isr_fingerprintLongpress()  { isrEvents.fingerprintLongpress = 1; }
void ARDUINO_ISR_ATTR isr_noseTouch()             { isrEvents.noseTouch = 1; }
void ARDUINO_ISR_ATTR isr_noseRelease()           { isrEvents.noseRelease = 1; }
void ARDUINO_ISR_ATTR isr_noseShortpress()        { isrEvents.noseShortpress = 1; }
void ARDUINO_ISR_ATTR isr_noseLongpress()         { isrEvents.noseLongpress = 1; }
void ARDUINO_ISR_ATTR isr_allShortpress()         { isrEvents.allShortpress = 1; }
void ARDUINO_ISR_ATTR isr_allLongpress()          { isrEvents.allLongpress = 1; }

/**
 * @brief Handles hard brown out events
 */
void _hardBrownOutHandler() {
    // Entry actions
    LOGF_ERROR(
        "HARD BROWN OUT DETECTED (V_BAT = %.2f V). Panic!\r\n",
        EFBoard.getBatteryVoltage()
    );
    EFBoard.disableWifi();
    // Try getting the LEDs into some known state
    EFLed.setBrightnessPercent(30);
    EFLed.clear();
    EFLed.setDragonNose(CRGB::Red);

    // Hard brown out can only be cleared by board reset
    while (1) {
        // Low brightness blink every few seconds
        EFLed.enablePower();
        EFLed.setDragonNose(CRGB::Red);
        esp_sleep_enable_timer_wakeup(200 * 1000);  // 200 ms
        EFLed.disablePower();
        // sleep most of the time.
        esp_sleep_enable_timer_wakeup(2 * 1000 * 1000);  // 2s
        esp_light_sleep_start();
        // TODO: Go to deep sleep, but save the reason so when waking up, we can blink and deep sleep again
    }
}

/**
 * @brief Handles soft brown out events
 */
void _softBrownOutHandler() {
    // Entry actions
    LOGF_WARNING(
        "Soft brown out detected (V_BAT = %.2f V). Aborting main loop and display warning LED.\r\n",
        EFBoard.getBatteryVoltage()
    );
    EFBoard.disableWifi();
    EFLed.clear();
    EFLed.enablePower();
    EFLed.setBrightnessPercent(40);

    // Soft brown out can only be cleared by board reset but can escalate to hard brown out
    while (1) {
        // Check for hard brown out
        pwrstate = EFBoard.updatePowerState();
        if (pwrstate == EFBoardPowerState::BAT_BROWN_OUT_HARD) {
            _hardBrownOutHandler();
        }

        // Blink LED to signal brown out to user
        for (uint8_t n = 0; n < 30; n++) {
            EFLed.enablePower();
            EFLed.setDragonNose(CRGB::Red);
            esp_sleep_enable_timer_wakeup(300 * 1000);
            esp_light_sleep_start();
            EFLed.disablePower();
            esp_sleep_enable_timer_wakeup(700 * 1000);
            esp_light_sleep_start();
        }

        // Log current battery level
        LOGF_INFO(
            "Battery voltage: %.2f V (%d %%)\r\n",
            EFBoard.getBatteryVoltage(),
            EFBoard.getBatteryCapacityPercent()
        );
    }
}

void batteryCheck() {
    EFBoardPowerState previousState = pwrstate;
    pwrstate = EFBoard.updatePowerState();
    if (previousState != pwrstate) {
        LOGF_DEBUG("Updated power state: %s\r\n", toString(pwrstate));
    }

    // Log battery level if battery powered
    if (EFBoard.isBatteryPowered()) {
        LOGF_INFO(
            "Battery voltage: %.2f V (%d %%)\r\n",
            EFBoard.getBatteryVoltage(),
            EFBoard.getBatteryCapacityPercent()
        );
    }

    // Handle brown out
    if (pwrstate == EFBoardPowerState::BAT_BROWN_OUT_HARD) {
        _hardBrownOutHandler();
    } else if (pwrstate == EFBoardPowerState::BAT_BROWN_OUT_SOFT) {
        _softBrownOutHandler();
    }
}

/**
 * @brief Displays a fancy bootup animation
 */
void boopupAnimation() {
    CRGB data[EFLED_TOTAL_NUM];
    fill_solid(data, EFLED_TOTAL_NUM, CRGB::Black);
    EFLed.setAll(data);
    delay(100);

    // Origin point. Power-Button is 11, 25. Make it originate from where the hand is
    constexpr int16_t pwrX = -30;
    constexpr int16_t pwrY = 16;
    uint8_t hue = 120;  // Green

    for (uint16_t n = 0; n < 30; n++) {
        uint16_t n_scaled = n * 7;
        if (n % 10) {
            // Low batteries might crash the boopup animation
            batteryCheck();
        }
        for (uint8_t i = 0; i < EFLED_TOTAL_NUM; i++) {
            int16_t dx = EFLedClass::getLEDPosition(i).x - pwrX;
            int16_t dy = EFLedClass::getLEDPosition(i).y - pwrY;
            float distance = sqrt(dx * dx + dy * dy);

            float intensity = wave_function(distance, n_scaled / 2 - 30, n_scaled * 2 + 20, 1.0);
            intensity = intensity * intensity; // sharpen wave

            // energy front
            uint8_t value = static_cast<uint8_t>(intensity * 255);
            data[i] = CHSV((hue + static_cast<uint16_t>(distance * 2.0f)) % 255, 240, value);
        }
        EFLed.setAll(data);
        delay(15);
    }
    EFLed.clear();
    delay(400);

    batteryCheck();
    // dragon awakens ;-)
    EFLed.setDragonEye(CRGB(10,0, 0));
    delay(60);
    EFLed.setDragonEye(CRGB(50,0, 0));
    delay(80);
    EFLed.setDragonEye(CRGB(100,0, 0));
    delay(150);
    EFLed.setDragonEye(CRGB(200,0, 0));
    delay(700);
    EFLed.setDragonEye(CRGB(100,0, 0));
    delay(80);
    EFLed.setDragonEye(CRGB(50,0, 0));
    delay(80);
    EFLed.setDragonEye(CRGB(10,0, 0));
    delay(60);
    EFLed.setDragonNose(CRGB::Black);
    delay(200);
}

/**
 * @brief Initial board setup. Called at boot / board reset.
 */
void setup() {
    // Init board
    EFBoard.setup();
    EFLed.init(ABSOLUTE_MAX_BRIGHTNESS);
    EFLed.setBrightnessPercent(40);  // We do not have access to the settings yet, default to 40
    boopupAnimation();
    
    // Touchy stuff
    EFTouch.init();
    EFTouch.attachInterruptOnTouch(EFTouchZone::Fingerprint, isr_fingerprintTouch);
    EFTouch.attachInterruptOnRelease(EFTouchZone::Fingerprint, isr_fingerprintRelease);
    EFTouch.attachInterruptOnShortpress(EFTouchZone::Fingerprint, isr_fingerprintShortpress);
    EFTouch.attachInterruptOnLongpress(EFTouchZone::Fingerprint, isr_fingerprintLongpress);
    EFTouch.attachInterruptOnTouch(EFTouchZone::Nose, isr_noseTouch);
    EFTouch.attachInterruptOnRelease(EFTouchZone::Nose, isr_noseRelease);
    EFTouch.attachInterruptOnShortpress(EFTouchZone::Nose, isr_noseShortpress);
    EFTouch.attachInterruptOnLongpress(EFTouchZone::Nose, isr_noseLongpress);
    EFTouch.attachInterruptOnShortpress(EFTouchZone::All, isr_allShortpress);
    EFTouch.attachInterruptOnLongpress(EFTouchZone::All, isr_allLongpress);

    // Get FSM going
    fsm.resume();
	
}

/**
 * @brief Main program loop
 */
void loop() {
    // Handler: ISR Events
    if (isrEvents.allLongpress) {
        fsm.queueEvent(FSMEvent::AllLongpress);
        isrEvents.noseLongpress = false;
        isrEvents.noseShortpress = false;
        isrEvents.noseRelease = false;
        isrEvents.fingerprintLongpress = false;
        isrEvents.fingerprintShortpress = false;
        isrEvents.fingerprintRelease = false;
        isrEvents.allLongpress = false;
        isrEvents.allShortpress = false;
    }
    if (isrEvents.allShortpress) {
        fsm.queueEvent(FSMEvent::AllShortpress);
        isrEvents.noseShortpress = false;
        isrEvents.noseRelease = false;
        isrEvents.fingerprintShortpress = false;
        isrEvents.fingerprintRelease = false;
        isrEvents.allShortpress = false;
    }
    if (isrEvents.fingerprintTouch) {
        fsm.queueEvent(FSMEvent::FingerprintTouch);
        isrEvents.fingerprintTouch = false;
    }
    if (isrEvents.fingerprintLongpress) {
        fsm.queueEvent(FSMEvent::FingerprintLongpress);
        isrEvents.fingerprintLongpress = false;
        isrEvents.fingerprintShortpress = false;
        isrEvents.fingerprintRelease = false;
    }
    if (isrEvents.fingerprintShortpress) {
        fsm.queueEvent(FSMEvent::FingerprintShortpress);
        isrEvents.fingerprintShortpress = false;
        isrEvents.fingerprintRelease = false;
    }
    if (isrEvents.fingerprintRelease) {
        fsm.queueEvent(FSMEvent::FingerprintRelease);
        isrEvents.fingerprintRelease = false;
    }

    if (isrEvents.noseTouch) {
        fsm.queueEvent(FSMEvent::NoseTouch);
        isrEvents.noseTouch = false;
    }
    if (isrEvents.noseLongpress) {
        fsm.queueEvent(FSMEvent::NoseLongpress);
        isrEvents.noseLongpress = false;
        isrEvents.noseShortpress = false;
        isrEvents.noseRelease = false;
    }
    if (isrEvents.noseShortpress) {
        fsm.queueEvent(FSMEvent::NoseShortpress);
        isrEvents.noseShortpress = false;
        isrEvents.noseRelease = false;
    }
    if (isrEvents.noseRelease) {
        fsm.queueEvent(FSMEvent::NoseRelease);
        isrEvents.noseRelease = false;
    }

    // Task: Handle FSM
    if (task_fsm_handle < millis()) {
        fsm.handle();
        task_fsm_handle = millis() + fsm.getTickRateMs();
    }

    // Task: Battery checks
    if (task_battery < millis()) {
        batteryCheck();
        task_battery = millis() + INTERVAL_BATTERY_CHECK;
    }
	
}

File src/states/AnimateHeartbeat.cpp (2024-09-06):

// MIT License
//
// Copyright 2024 Eurofurence e.V. 
// 
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
#include <EFLed.h>
#include <EFLogging.h>

#include "FSMState.h"

const char *AnimateHeartbeat::getName() {
    return "AnimateHeartbeat";
}

bool AnimateHeartbeat::shouldBeRemembered() {
    return true;
}

const unsigned int AnimateHeartbeat::getTickRateMs() {
    return 60;
}

void AnimateHeartbeat::entry() {
    this->tick = 0;
}

void AnimateHeartbeat::run() {
    CRGB data[EFLED_TOTAL_NUM];
    fill_solid(data, EFLED_TOTAL_NUM, CRGB::Black);

    for (uint8_t i = 0; i < EFLED_TOTAL_NUM; i++) {
        float dx = EFLedClass::getLEDPosition(i).x - EFLedClass::getLEDPosition(EFLED_DRAGON_EYE_IDX).x;
        float dy = EFLedClass::getLEDPosition(i).y - EFLedClass::getLEDPosition(EFLED_DRAGON_EYE_IDX).y;
        float distance = sqrt(dx * dx + dy * dy);

        // LEDs further away from the eye lag behind
        float t = tick / 40.0 - distance / 80.0;

        float intensity = sin(t * 1.0 * M_PI);
        intensity = intensity < 0.0 ? 0.0 : intensity;

        uint8_t value = static_cast<uint8_t>(intensity * 255);
        data[i] = CHSV(this->globals->animHeartbeatHue, 255, value);
    }

    EFLed.setAll(data);

    // Prepare next tick
    this->tick = this->tick + this->globals->animHeartbeatSpeed + 1;
}

std::unique_ptr<FSMState> AnimateHeartbeat::touchEventFingerprintShortpress() {
    if (this->isLocked()) {
        return nullptr;
    }

    return std::make_unique<MenuMain>();
}

std::unique_ptr<FSMState> AnimateHeartbeat::touchEventFingerprintLongpress() {
    return this->touchEventFingerprintShortpress();
}

std::unique_ptr<FSMState> AnimateHeartbeat::touchEventNoseRelease() {
    if (this->isLocked()) {
        return nullptr;
    }

    uint8_t oldHue = this->globals->animHeartbeatHue;
    this->globals->animHeartbeatHue = random(0, 255);
    if (abs(oldHue - this->globals->animHeartbeatHue) < 20) {
        // If random is too close to last one, make it more different
        this->globals->animHeartbeatHue = (this->globals->animHeartbeatHue + 20) % 255;
    }
    this->is_globals_dirty = true;

    EFLed.setDragonEye(CRGB::Black);
    delay(100);
    EFLed.setDragonEye(CHSV(this->globals->animHeartbeatHue, 255, 255));
    delay(300);
    EFLed.setDragonEye(CRGB::Black);

    this->tick = 0;
    return nullptr;
}

std::unique_ptr<FSMState> AnimateHeartbeat::touchEventNoseShortpress() {
    if (this->isLocked()) {
        return nullptr;
    }

    this->globals->animHeartbeatSpeed = (this->globals->animHeartbeatSpeed + 1) % 3;
    this->is_globals_dirty = true;

    CRGB data[EFLED_EFBAR_NUM];
    fill_solid(data, EFLED_EFBAR_NUM, CRGB::Black);
    EFLed.setEFBar(data);
    delay(100);
    fill_solid(data, this->globals->animHeartbeatSpeed + 1, CRGB::Red);
    EFLed.setEFBar(data);
    delay(300);
    fill_solid(data, this->globals->animHeartbeatSpeed + 1, CRGB::Black);
    EFLed.setEFBar(data);
    delay(200);
    fill_solid(data, this->globals->animHeartbeatSpeed + 1, CRGB::Red);
    EFLed.setEFBar(data);
    delay(400);

    return nullptr;
}

std::unique_ptr<FSMState> AnimateHeartbeat::touchEventAllLongpress() {
    this->toggleLock();
    return nullptr;
}

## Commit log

2024-08-22 Create some easy to use LED wrapper with safety guards for maximum LED brightness
2024-08-22 Refactor ota-badge libs to use Arduino "singleton" pattern
2024-08-22 ota-badge: Add touch zone based ISR support (touched, released, shortpress, longpress) to EFTouch lib
    [main.cpp]
2024-08-22 ota-badge: Improve OTA visuals and allow for visual debugging using on-board LEDs
2024-08-22 ota-badge: Implement finite state machine that reacts to touch interrupts. Create basic menu structure and allow to enter/exit OTA mode on-demand.
2024-08-22 ota-badge: Initialize ADC and battery voltage sense pin during board setup
2024-08-22 ota-badge: Create functions to measure battery voltage and approximate battery capacity using a discharge function
2024-08-22 ota-badge: Create task to periodically log battery voltage / charge when battery is detected
2024-08-22 ota-badge: Implement board power state management and brown out handling (soft + hard)
    [main.cpp]
2024-08-22 ota-badge: Improve touch interrupt handling. Only trigger one of: Release, Shortpress, Longpress per iteration
    [main.cpp]
2024-08-22 ota-badge: Add methods to EFLed to set all LEDs based on a full color array and to set all LEDs to a single color
2024-08-22 Fill empty dragon LEDs during PrideFlag operation mode with cycling flag colors
2024-08-26 Ignore KiCad temp files
2024-08-26 Add KiCad project files (schematic, PCB, ...)
    [efbadge.csv, efbadge.kicad_pcb, efbadge.kicad_sch]
2024-08-26 Make schematic fit page area
    [efbadge.kicad_sch]
2024-08-26 Create PDF and PNG exports of the badge schematics
2024-08-27 Create note about availability of KiCad project files inside hardware directory
2024-08-31 Refine battery values
    In my tests, the ESP runs with the batteries at 3,28. it just fails to start up at below VBAT 3,3V. But if the batteries are given a few seconds to recover, it works. And while it is running, we do get quiet a bit of more runtime if we allow going lower. I'll try to improve the brown-out handling in a later commit.
2024-08-31 Tweak power settings
2024-08-31 Typo fix and whitespace cleanup
    [main.cpp]
2024-09-01 Tweak battery values to something slightly more safe
    After some discussion.
2024-09-02 Remove blink LED task code as task handler was removed by previous commit but actual implementation code did not get cleaned up
2024-09-02 Persist current FSM globals into NVS if requested by state
2024-09-02 Remove sub state settings menu from DisplayPrideFlag and allow switching current flag/pattern by touching fingerprint zone in normal operation state
2024-09-02 Fix pin mapping in EFTouch constructor
2024-09-03 Introduce constant for battery check
2024-09-04 Enable positional animation of LEDs
2024-09-04 Decrease touch-delay limits
    I have been testing around in some modes and only now really realized that a 'Release' event is not a ShortTouch.
    Which is okay that we do it like this. We basically get three modes out of a button: Tap, ShortPress, LongPress.
    But when playing around, it felt very sluggish. I thought the ShortPress mode was broken because it felt like a LongPress. :P
    I researched online on UX studies and what kind of reaction people expect from Touch-UIs. Usually, a touch->interaction latency should be below 300ms. This is the Tap -> Response delay and not necessarily a good value for 'ShortPress' above them. But it gives a lower bound. I went with 500ms which does feel like a n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
2024-09-05 Remove initial delay
    After tweaking my flashing settings, it now always works. Does it work for you as well? If so, let's remove this annoying delay at the start.
    Also tweaked the FastLED delay in the hope to reduce the flicker of the LEDs, but it is still there. =/
2024-09-06 Tweak a bunch of values
    Sorry for yet another mixed-bag PR, but the more I test around, the better values I find I think.
    The 'longPress' can be verbalized/explained by 'hold the button and count to three' -> this naturally *almost* works. I decreased the delay from 2000ms to 1800ms, then it works nicely like this with 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
2024-09-06 Improve MainMenu, add brightness control
    Somehow it is not yet correctly persisted. I think I am loading globals incorrectly in main.cpp and that makes it reset this to the default value.
    [main.cpp]
2024-09-06 Fix NVS persistence storage of ledBrightnessPercent
2024-09-06 Properly restore global LED brightness setting on FSM resume
2024-09-06 Fix: Battery voltage reading
    It seems to be off. Trying to make it a bit more robust and the badge go less into soft_brownout_detection if it is not really needed.
2024-09-06 fix: update led brightness handling and delay timings
    [main.cpp]
2024-09-06 Implement button locking to all main run states
2024-09-06 Fix multitouch race condition when lifting fingers from touch zones
2024-09-06 fix: improve battery voltage calculation accuracy
    The old measurements were off and always cut off a lot of battery runtime from the badges!
2024-09-07 fix: improve low power handling
    [main.cpp]
2024-09-07 feat: add autoflash script for automatic device flashing
    Introduce `autoflash.sh` to continuously monitor a specified device
    port, automatically flash firmware upon device detection, and log
    results. This enhances the flashing process by making it more efficient
    and less manual.
    Yay for two days of continuous preparing and flashing! :D
2024-09-07 Do battery checks in the boopup
2024-09-07 Tweak power value
2024-09-10 Make out-of-power state a bit more visible
2024-09-17 Replace hardware files publication note with link to KiCad software
2024-09-18 Fix Arial font usage on PCB back silkscreen
    [efbadge.kicad_pcb]
2024-09-23 Add manual and warning about LED brightness
    Add manual and warning about LED brightness to the README
